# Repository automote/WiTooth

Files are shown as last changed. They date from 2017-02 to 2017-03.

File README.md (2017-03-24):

# WiTooth

The WiTooth is based on Espressif ESP32 WiFi-BT-BLE SoC (System on Chip), ESP32 contains two low-power Xtensa® 32-bit LX6 microprocessors running at 80 MHz. Features include:

 * Integrated 802.11 BGN WiFi transceiver
 * Integrated dual-mode Bluetooth (classic and BLE)
 * Dual-core Tensilica LX6 microprocessor
 * Up to 240MHz clock frequency
 * 520kB internal SRAM
 * 10-electrode capacitive touch support
 * Hardware accelerated encryption (AES, SHA2, ECC, RSA-4096)
 * 2.2 to 3.6V operating range
 * 2.5 µA deep sleep current
 * 3 SPI, 2 I2C, 2 UART
 * 16 PWM outputs
 * 2 DAC
 * 2 I2S
 * 18 analog-to-digital converter (ADC) channels
 
## Platform Features

 * Compatible with Arduino IDE
 * USB powered
 * CP2102 USB-to-UART Bridge
 * Extended breadboard compatible headers
 * UART, SPI, I2C
 * On-board RESET

## Changelog
 - v1.1
	+ Grounding via added
	+ Version bumped to 1.1
 - v1.0
	+ Updated 2N3904 symbol and footprint
	+ removed JTAG headers
 
## Maintainers

The WiTooth is maintained by thingTronics Innovations.

Main contributor:
 * Manohar Bompella @<manohar.bompella@thingtronics.com>
 * Poornima Nagesh @<poornima.nagesh@thingtronics.com>
 * Lovelesh Patel @<lovelesh.patel@thingtronics.com>

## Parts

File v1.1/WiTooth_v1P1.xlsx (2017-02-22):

Reference | Quantity | Value | Footprint | DESC | MFG_NAME | MPN | PCB Package | 1 | 100 | 500 | 1000 | 10 PCB | 100 PCB | 1000 PCB | Purchased cost for 100
C1 C4 | 2 | 10uF | Capacitors_SMD:C_0805_HandSoldering | Multilayer Ceramic Capacitors MLCC - SMD/SMT 10 uF 16V 10% | Yageo | AC0805KRX7R9BB103 | 805 | 3.5 | 2.1 | 2.1 | 2.1 | 7 | 4.2 | 4.2
C12 | 1 | 100uF | Capacitors_SMD:C_1206_HandSoldering | Multilayer Ceramic Capacitors MLCC - SMD/SMT 100 uF 16V 10% | Yageo | AC0805KRX7R9BB103 | 805 | 3.5 | 2.1 | 2.1 | 2.1 | 3.5 | 2.1 | 2.1
C13 C6 | 2 | 1uF | Capacitors_SMD:C_0805_HandSoldering | Multilayer Ceramic Capacitors MLCC - SMD/SMT 1 uF 16V 10% | Yageo | AC0805KRX7R9BB103 | 805 | 3.5 | 2.1 | 2.1 | 2.1 | 7 | 4.2 | 4.2
C2 | 1 | 0.1uF | Capacitors_SMD:C_0805_HandSoldering | Multilayer Ceramic Capacitors MLCC - SMD/SMT 0.1 uF 16V 10% | Yageo | AC0805KRX7R9BB103 | 805 | 3.5 | 2.1 | 2.1 | 2.1 | 3.5 | 2.1 | 2.1
C3 C5 | 2 | 47pF | Capacitors_SMD:C_0805_HandSoldering | Multilayer Ceramic Capacitors MLCC - SMD/SMT 47 pF 16V 10% | Yageo | AC0805KRX7R9BB103 | 805 | 3.5 | 2.1 | 2.1 | 2.1 | 7 | 4.2 | 4.2
C10 C14 C7 C8 | 4 | 1nF | Capacitors_SMD:C_0805_HandSoldering | Multilayer Ceramic Capacitors MLCC - SMD/SMT 1 nF 16V 10% | Yageo | AC0805KRX7R9BB103 | 805 | 3.5 | 2.1 | 2.1 | 2.1 | 14 | 8.4 | 8.4
C11 C9 | 2 | 27pF | Capacitors_SMD:C_0805_HandSoldering | Multilayer Ceramic Capacitors MLCC - SMD/SMT 27 pF 16V 10% | Yageo | AC0805KRX7R9BB103 | 805 | 3.5 | 2.1 | 2.1 | 2.1 | 7 | 4.2 | 4.2
D1 | 1 | PWR_GREEN | LEDs:LED_0805 | GREEN led for power indication | Kingbright | AP2012SRCPRV | 805 | 9.8 | 4.76 | 4.76 | 4.55 | 9.8 | 4.76 | 4.55
D2 D3 | 2 | YELLOW | LEDs:LED_0805 | Yellow led for Data Receiving indication | Kingbright | AP2012SRCPRV | 805 | 9.1 | 4.76 | 4.76 | 4.55 | 18.2 | 9.52 | 9.1
D4 | 1 | CONN_LED | LEDs:LED_0805 | RED led for Data Connection indication | Kingbright | AP2012SRCPRV | 805 | 9.8 | 4.76 | 4.76 | 4.55 | 9.8 | 4.76 | 4.55
D5 | 1 | USER_LED | LEDs:LED_0805 | GREEN led for User application | Kingbright | AP2012SRCPRV | 805 | 9.8 | 4.76 | 4.76 | 4.55 | 9.8 | 4.76 | 4.55
P1 | 1 | USB_A_MALE (DNM) | USB:usb-PCB_male | USB A MALE CONNECTOR pcb (DNM) | ******** | ********* |  |  |  |  |  | 0 | 0 | 0
P4 P5 | 2 | CONN_01X20 | Pin_Headers:Pin_Header_Straight_1x20_Pitch2.54mm | Worth Elekronik | 61300211121 |  | 8.4 | 7.42 | 6.3 | 6.23 | 6.23 | 14.84 | 12.6 | 12.46
Q1 Q2 | 2 | 2N3904-MMBT | TO_SOT_Packages_SMD:SOT-23_Handsoldering |  |  |  |  |  |  |  |  | 0 | 0 | 0
R10 | 1 | 5K | Resistors_SMD:R_0805_HandSoldering | Current Sense Resistors - SMD 0805 0.002ohm 1% AEC-Q200 | ROHM Semiconductor | PMR10EZPFV2L00 | 805 | 7.7 | 2.8 | 2.8 | 2.59 | 7.7 | 2.8 | 2.59
R11 R12 R13 R14 R7 | 5 | 470E | Resistors_SMD:R_0805_HandSoldering | Current Sense Resistors - SMD 0805 0.002ohm 1% AEC-Q200 | ROHM Semiconductor | PMR10EZPFV2L00 | 805 | 7.7 | 2.8 | 2.8 | 2.59 | 38.5 | 14 | 12.95
R15 R16 | 2 | 0E | Resistors_SMD:R_0805_HandSoldering | Current Sense Resistors - SMD 0805 0.002ohm 1% AEC-Q200 | ROHM Semiconductor | PMR10EZPFV2L00 | 805 | 7.7 | 2.8 | 2.8 | 2.59 | 15.4 | 5.6 | 5.18
R1 R2 R6 | 3 | 12K | Resistors_SMD:R_0805_HandSoldering | Current Sense Resistors - SMD 0805 0.002ohm 1% AEC-Q200 | ROHM Semiconductor | PMR10EZPFV2L00 | 805 | 7.7 | 2.8 | 2.8 | 2.59 | 23.1 | 8.4 | 7.77
R4 R8 R9 | 3 | 1K | Resistors_SMD:R_0805_HandSoldering | Current Sense Resistors - SMD 0805 0.002ohm 1% AEC-Q200 | ROHM Semiconductor | PMR10EZPFV2L00 | 805 | 7.7 | 2.8 | 2.8 | 2.59 | 23.1 | 8.4 | 7.77
R3 R5 | 2 | 27E | Resistors_SMD:R_0805_HandSoldering | Current Sense Resistors - SMD 0805 0.002ohm 1% AEC-Q200 | ROHM Semiconductor | PMR10EZPFV2L00 | 805 | 7.7 | 2.8 | 2.8 | 2.59 | 15.4 | 5.6 | 5.18
SW1 | 1 | RESET | switches:SW_SPST_B3U-1000P_SUNROM | TACTILE SWITCH 3X4X2MM SMD 2-PIN | SUNROM | 4982 | SMD | 4 | 3.6 | 3.6 | 3.6 | 4 | 3.6 | 3.6
SW2 | 1 | BOOT | switches:SW_SPST_B3U-1000P_SUNROM | TACTILE SWITCH 3X4X2MM SMD 2-PIN | SUNROM | 4982 | SMD | 4 | 3.6 | 3.6 | 3.6 | 4 | 3.6 | 3.6
SW3 | 1 | USER_SW | switches:SW_SPST_B3U-1000P_SUNROM | TACTILE SWITCH 3X4X2MM SMD 2-PIN | SUNROM | 4982 | SMD | 4 | 3.6 | 3.6 | 3.6 | 4 | 3.6 | 3.6
U1 | 1 | AMS1117-3V3 | TO_SOT_Packages_SMD:SOT-223 | LM1117 800-mA Low-Dropout Linear Regulator | Texas Instruments | LM1117 | SOT-233 | 9 | 6 | 4 | 3 | 9 | 6 | 3
U2 | 1 | CP2102 | smt-qfn:QFN-28-1EP_5x5mm_Pitch0.5mm | Single-Chip USB to UART Data Transfer | Silicon Labs | CP2102-GM | QFN-28 | 90 | 85 | 80 | 70 | 90 | 85 | 70
U3 | 1 | ESP-32_WROOM32_Rectangle | ESP-32:ESP32-WROOM_SMALLER_FOOTPRINT | ESP32-WROOM wifi Chip | WROOM |  |  | 650 | 650 | 650 | 600 | 650 | 650 | 600
Y1 | 1 | Crystal | Crystals:Crystal_SMD_0603-2pin_6.0x3.5mm_HandSoldering | 32.768 Khz RTC Crystals | SUNROM | 3964 | SMD | 15 | 13.5 | 13.5 | 13.5 | 15 | 13.5 | 13.5
 |  |  |  |  |  |  |  |  |  |  | TOTAL | 1010.64 | 875.9 | 803.35
 |  |  |  |  |  |  |  |  |  |  |  | 350
 |  |  |  |  |  |  |  |  |  |  |  | 1510.64

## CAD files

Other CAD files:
v1.0/MECH/cover.CATpart.CATPart
v1.0/MECH/switch.CATPart
v1.0/MECH/upper_by_part.CATPart

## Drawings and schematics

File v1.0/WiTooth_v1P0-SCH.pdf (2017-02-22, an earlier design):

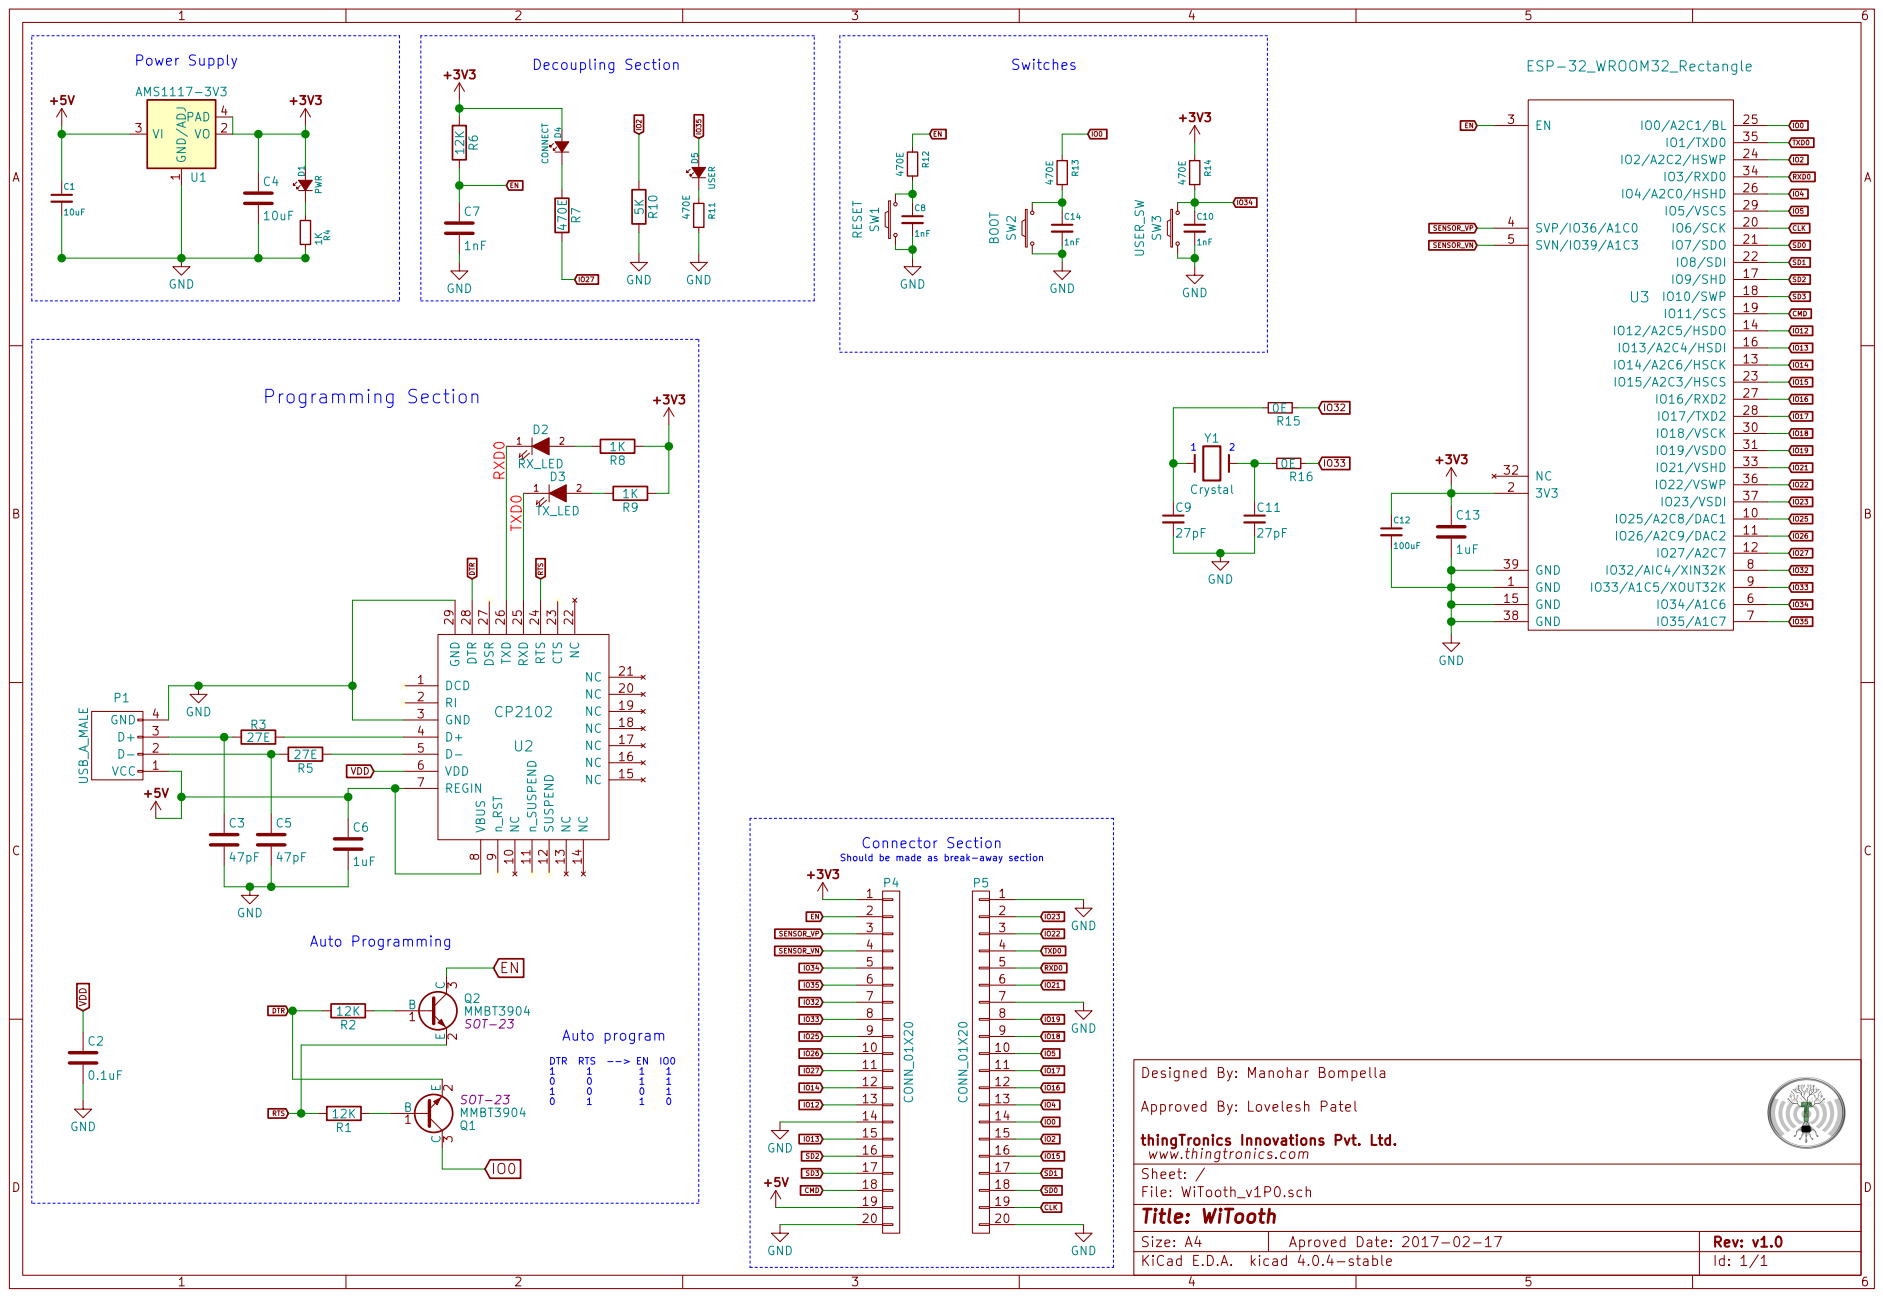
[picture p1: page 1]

Should be made as break-away section Programming Section

9 NC 10 NC 20 n_SUSPEND 11 NC 21 SUSPEND 12 NC 22 NC 13 CTS 23 NC 14 RTS 24 NC 15 RXD 25 NC 16 TXD 26 NC 17 DSR 27 NC 18 DTR 28 NC 19 GND 29 U2 CP2102 R5

Approved By: Lovelesh Patel

thingTronics Innovations Pvt. Ltd.
File: WiTooth_v1P0.sch Sheet: / www.thingtronics.com

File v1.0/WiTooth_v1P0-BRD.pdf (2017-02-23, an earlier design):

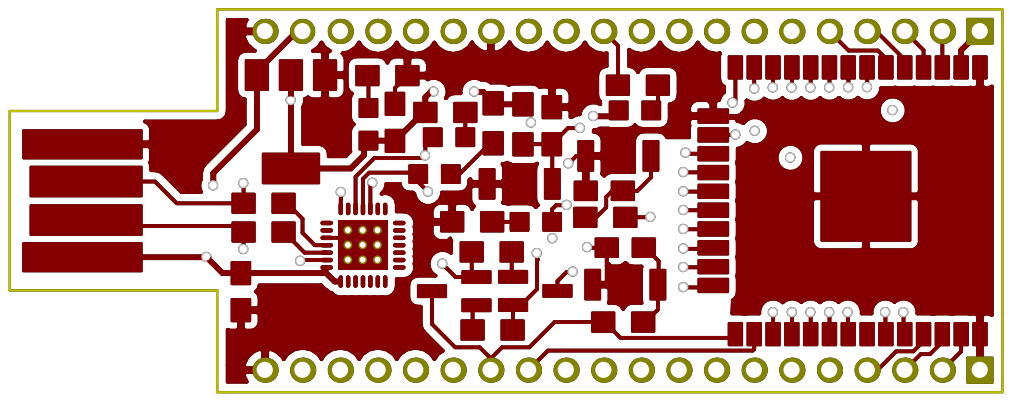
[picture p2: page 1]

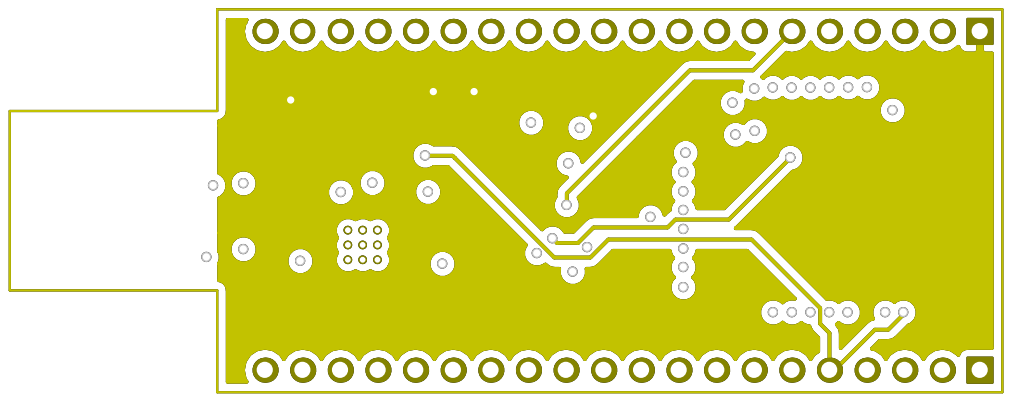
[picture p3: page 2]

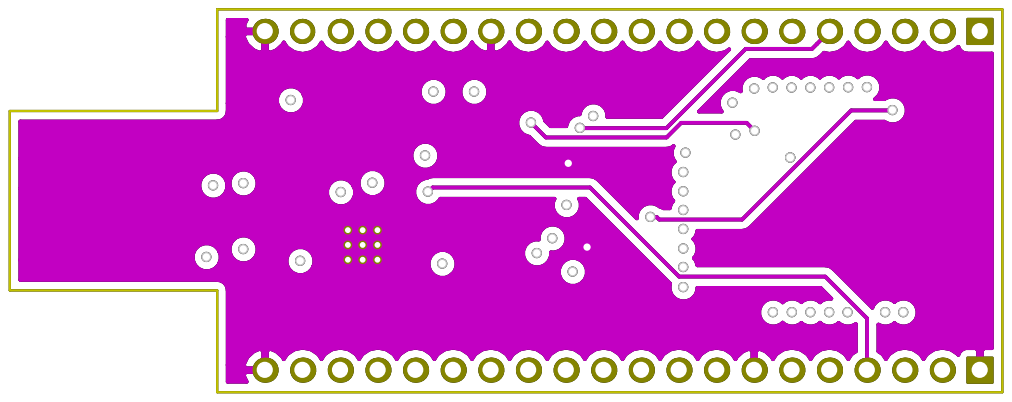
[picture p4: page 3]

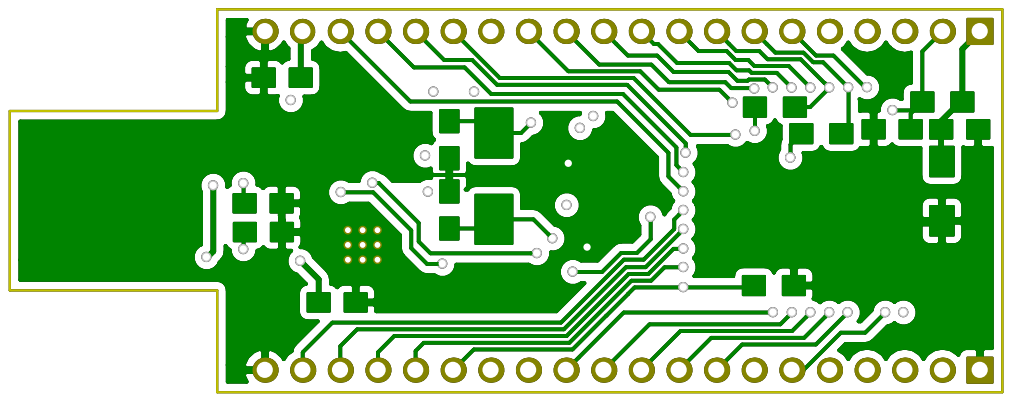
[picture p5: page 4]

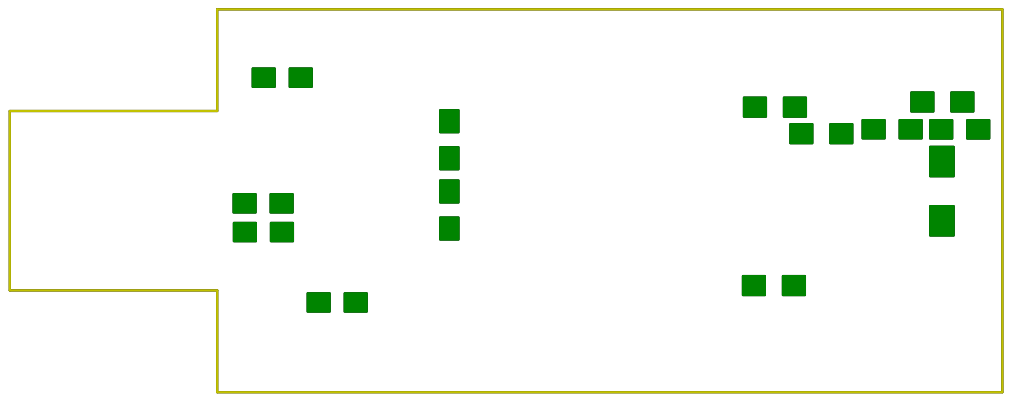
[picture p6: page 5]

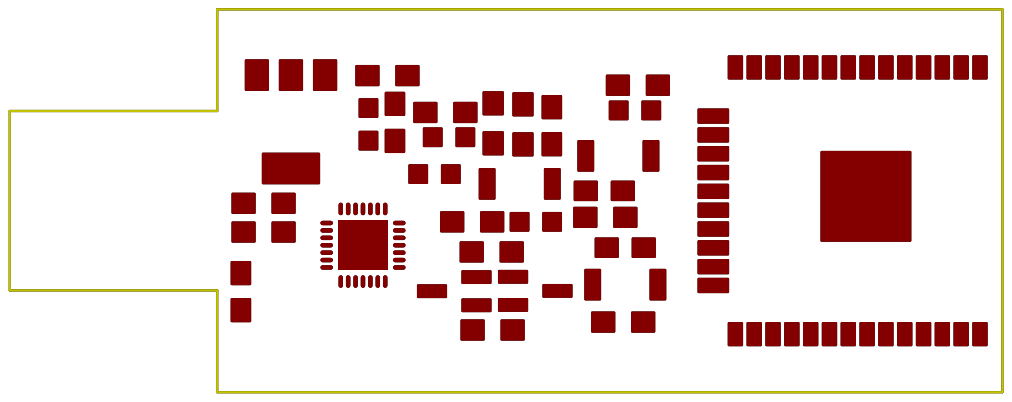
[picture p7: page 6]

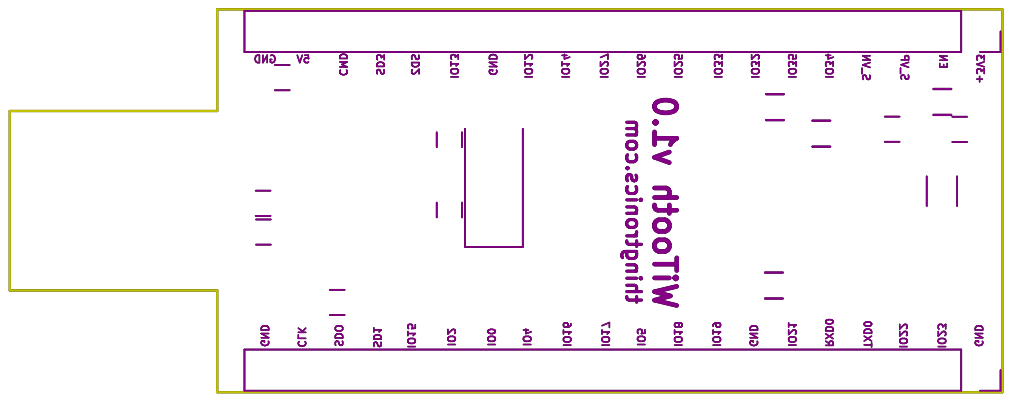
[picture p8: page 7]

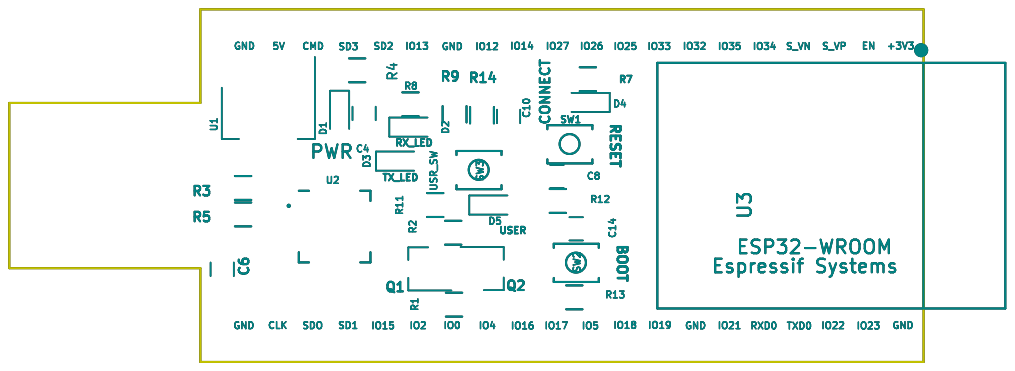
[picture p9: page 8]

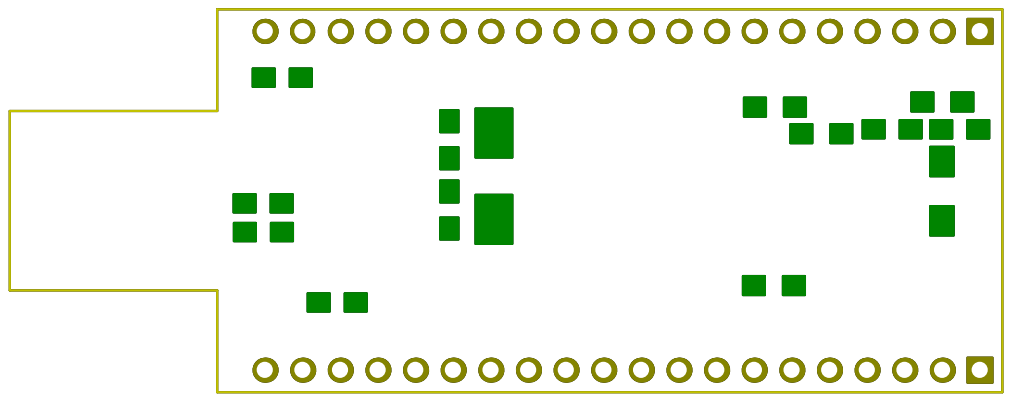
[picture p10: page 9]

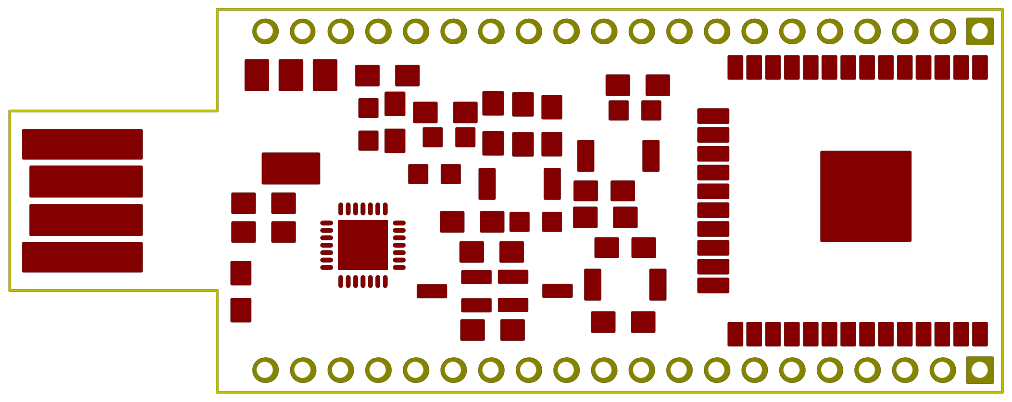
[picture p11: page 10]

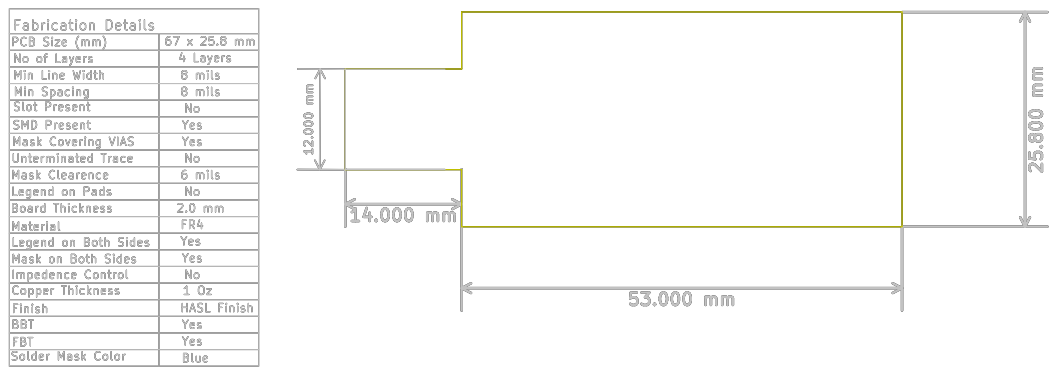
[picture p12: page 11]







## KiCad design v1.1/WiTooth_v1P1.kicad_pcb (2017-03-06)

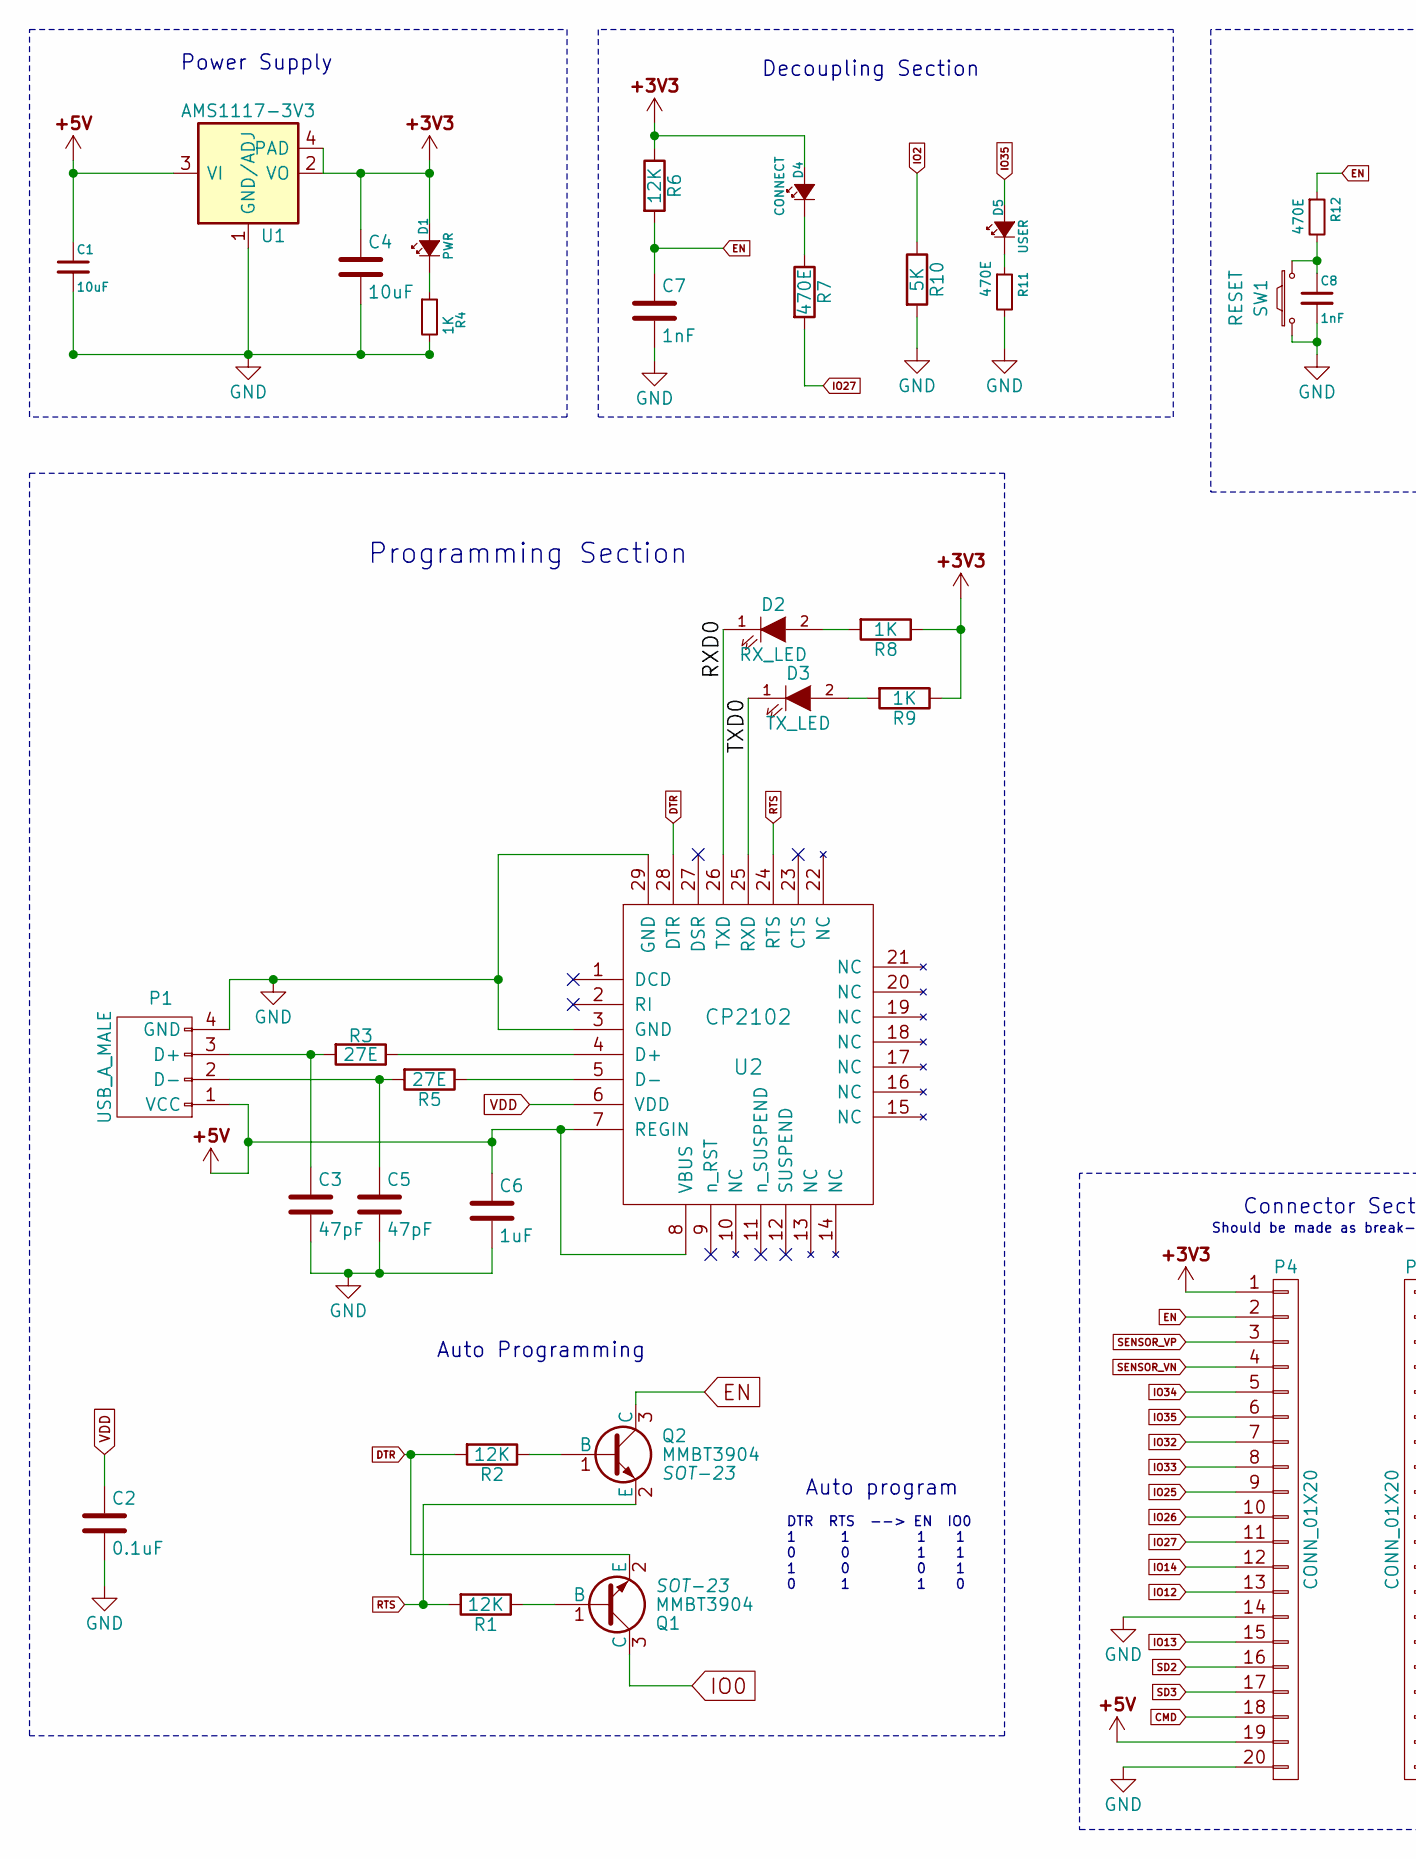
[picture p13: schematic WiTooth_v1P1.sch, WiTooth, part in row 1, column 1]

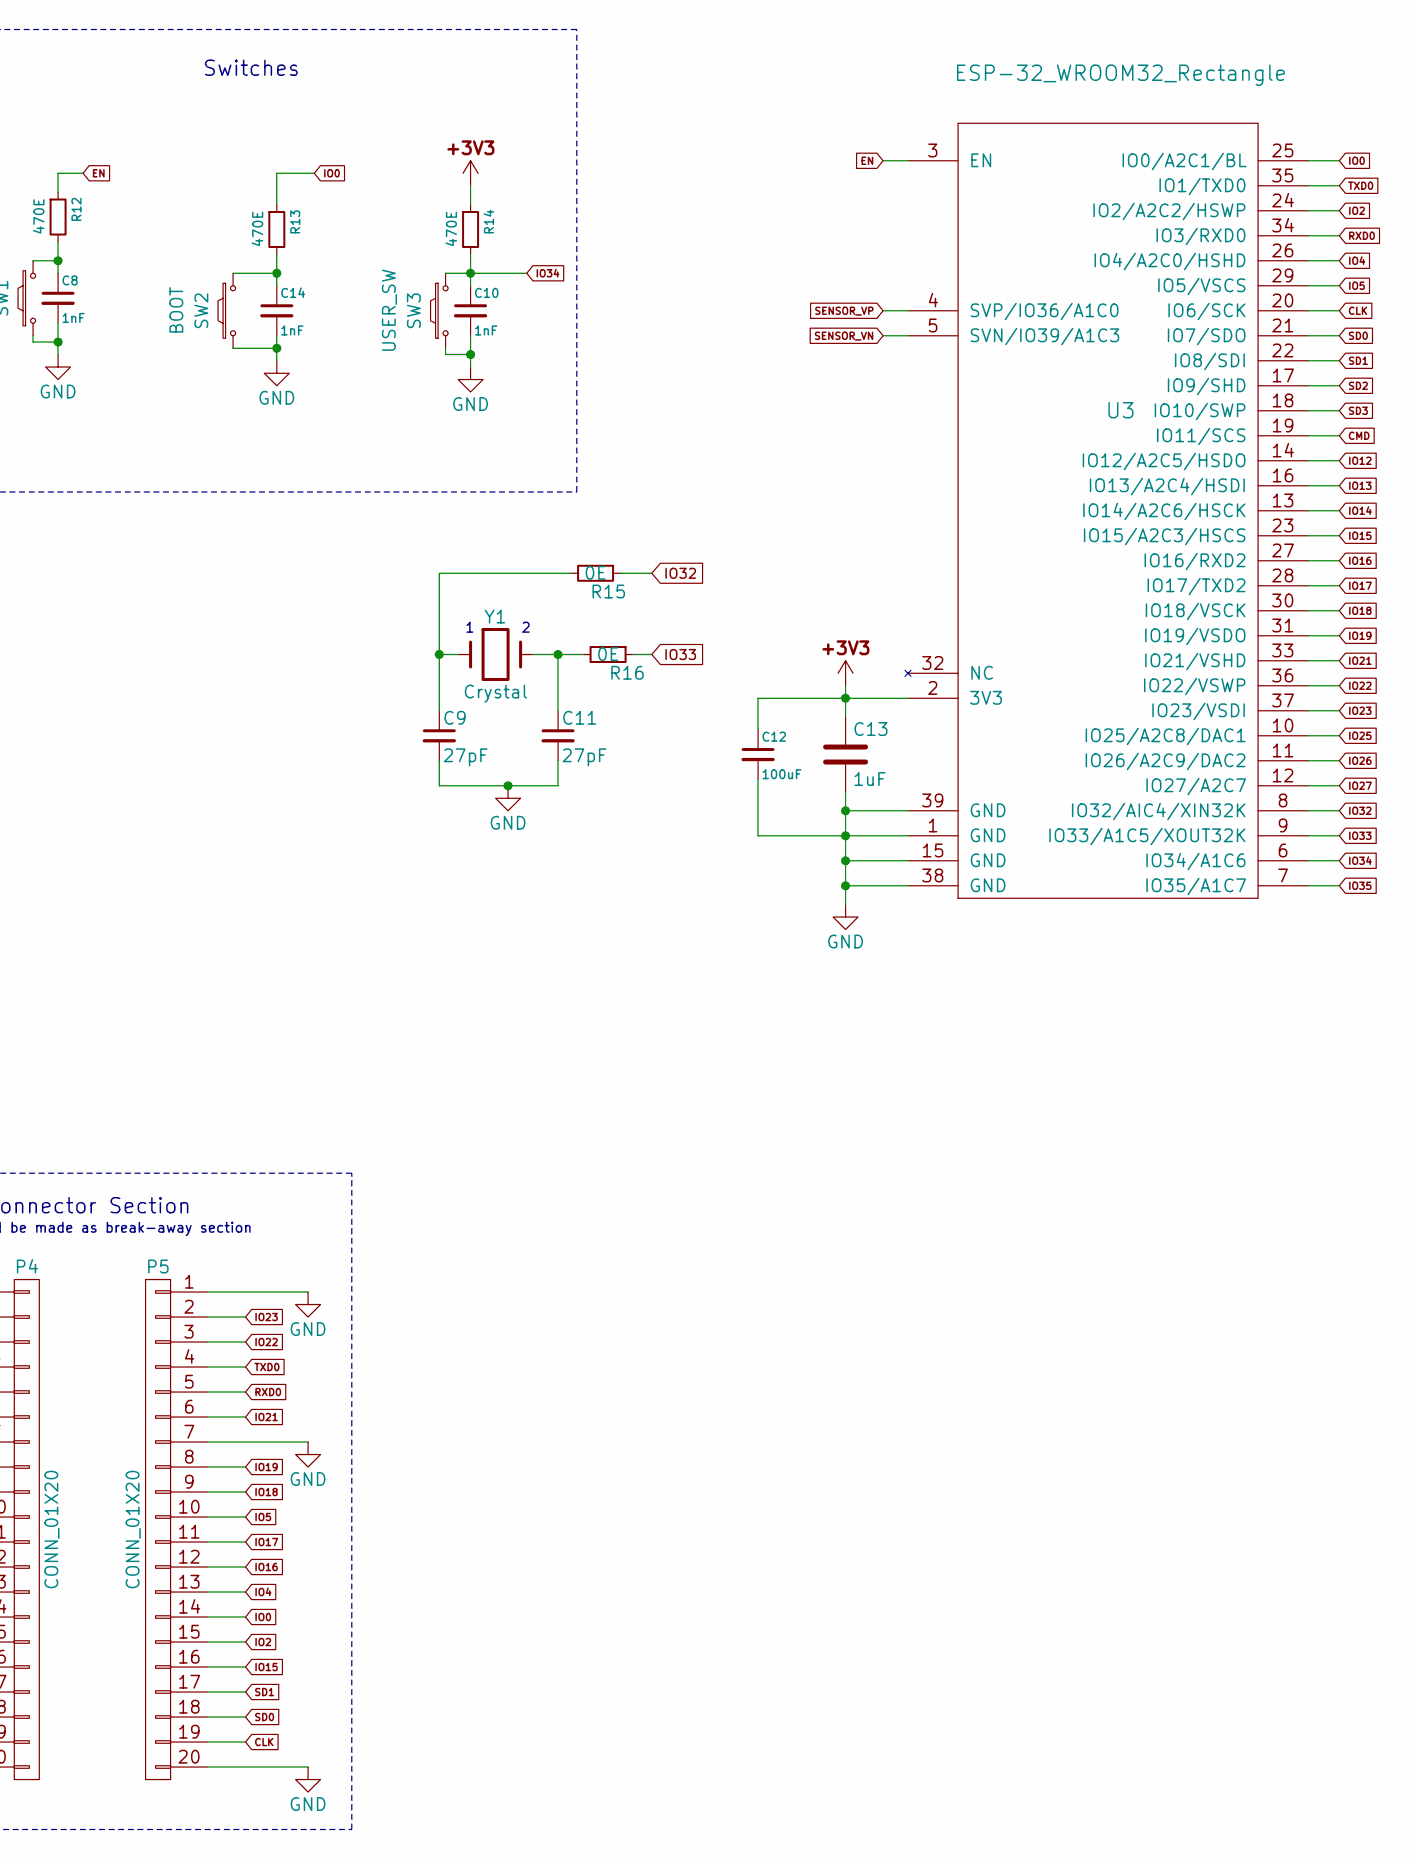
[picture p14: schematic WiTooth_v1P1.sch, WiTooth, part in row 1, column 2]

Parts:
C1, C4: 10uF; C_0805_HandSoldering
C2: 0.1uF; C_0805_HandSoldering
C3, C5: 47pF; C_0805_HandSoldering
C6, C13: 1uF; C_0805_HandSoldering
C7, C8, C10, C14: 1nF; C_0805_HandSoldering
C9, C11: 27pF; C_0805_HandSoldering
C12: 100uF; C_1206_HandSoldering
D1: PWR; LED_0805
D2: RX_LED; LED_0805
D3: TX_LED; LED_0805
D4: CONNECT; LED_0805
D5: USER; LED_0805
P1: USB_A_MALE; usb-PCB_male; MPN *********
P4, P5: CONN_01X20; Pin_Header_Straight_1x20_Pitch2.54mm
Q1, Q2: MMBT3904; SOT-23
R1, R2, R6: 12K; R_0805_HandSoldering
R3, R5: 27E; R_0805_HandSoldering
R4, R8, R9: 1K; R_0805_HandSoldering
R7, R11, R12, R13, R14: 470E; R_0805_HandSoldering
R10: 5K; R_0805_HandSoldering
R15, R16: 0E; R_0805_HandSoldering
SW1: RESET; SW_SPST_B3U-1000P_SUNROM
SW2: BOOT; SW_SPST_B3U-1000P_SUNROM
SW3: USER_SW; SW_SPST_B3U-1000P_SUNROM
U1: AMS1117-3V3; SOT-223; MPN LM1117
U2: CP2102; QFN-28-1EP_5x5mm_Pitch0.5mm
U3: ESP-32_WROOM32_Rectangle; ESP32-WROOM_SMALLER_FOOTPRINT
Y1: Crystal; Crystal_SMD_0603-2pin_6.0x3.5mm_HandSoldering

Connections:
+3V3: C4.1, C12.1, C13.1, D1.2 (A), D4.2 (A), P4.1, R6.1, R8.1, R9.1, R14.1, U1.2 (VO), U1.4 (PAD), U3.2 (3V3)
+5V: C1.1, C6.1, P1.1 (VCC), P4.19, U1.3 (VI), U2.7 (REGIN), U2.8 (VBUS)
CLK: P5.19, U3.20 (IO6/SCK)
CMD: P4.18, U3.19 (IO11/SCS)
DTR: Q1.2 (E), R2.2, U2.28 (DTR)
EN: C7.1, P4.2, Q2.3 (C), R6.2, R12.1, U3.3 (EN)
GND: C1.2, C2.2, C3.2, C4.2, C5.2, C6.2, C7.2, C8.2, C9.2, C10.2, C11.2, C12.2, C13.2, C14.2, P1.4 (GND), P4.14, P4.20, P5.1, P5.7, P5.20, R4.2, R10.2, R11.2, SW1.1, SW2.1, SW3.1, U1.1 (GND/ADJ), U2.3 (GND), U2.29 (GND), U3.1 (GND), U3.15 (GND), U3.38 (GND), U3.39 (GND)
IO0: P5.14, Q1.3 (C), R13.1, U3.25 (IO0/A2C1/BL)
IO2: P5.15, R10.1, U3.24 (IO2/A2C2/HSWP)
IO4: P5.13, U3.26 (IO4/A2C0/HSHD)
IO5: P5.10, U3.29 (IO5/VSCS)
IO12: P4.13, U3.14 (IO12/A2C5/HSDO)
IO13: P4.15, U3.16 (IO13/A2C4/HSDI)
IO14: P4.12, U3.13 (IO14/A2C6/HSCK)
IO15: P5.16, U3.23 (IO15/A2C3/HSCS)
IO16: P5.12, U3.27 (IO16/RXD2)
IO17: P5.11, U3.28 (IO17/TXD2)
IO18: P5.9, U3.30 (IO18/VSCK)
IO19: P5.8, U3.31 (IO19/VSDO)
IO21: P5.6, U3.33 (IO21/VSHD)
IO22: P5.3, U3.36 (IO22/VSWP)
IO23: P5.2, U3.37 (IO23/VSDI)
IO25: P4.9, U3.10 (IO25/A2C8/DAC1)
IO26: P4.10, U3.11 (IO26/A2C9/DAC2)
IO27: P4.11, R7.2, U3.12 (IO27/A2C7)
IO32: P4.7, R15.1, U3.8 (IO32/AIC4/XIN32K)
IO33: P4.8, R16.1, U3.9 (IO33/A1C5/XOUT32K)
IO34: C10.1, P4.5, R14.2, SW3.2, U3.6 (IO34/A1C6)
IO35: D5.2 (A), P4.6, U3.7 (IO35/A1C7)
unnamed: C3.1, P1.3 (D+), R3.2
unnamed: C5.1, P1.2 (D-), R5.2
unnamed: C8.1, R12.2, SW1.2
unnamed: C9.1, R15.2, Y1.1
unnamed: C11.1, R16.2, Y1.2
unnamed: C14.1, R13.2, SW2.2
unnamed: D1.1 (K), R4.1
unnamed: D2.2 (A), R8.2
unnamed: D3.2 (A), R9.2
unnamed: D4.1 (K), R7.1
unnamed: D5.1 (K), R11.1
unnamed: Q1.1 (B), R1.1
unnamed: Q2.1 (B), R2.1
unnamed: R3.1, U2.4 (D+)
unnamed: R5.1, U2.5 (D-)
RTS: Q2.2 (E), R1.2, U2.24 (RTS)
RXD0: D2.1 (K), P5.5, U2.26 (TXD), U3.34 (IO3/RXD0)
SD0: P5.18, U3.21 (IO7/SDO)
SD1: P5.17, U3.22 (IO8/SDI)
SD2: P4.16, U3.17 (IO9/SHD)
SD3: P4.17, U3.18 (IO10/SWP)
SENSOR_VN: P4.4, U3.5 (SVN/IO39/A1C3)
SENSOR_VP: P4.3, U3.4 (SVP/IO36/A1C0)
TXD0: D3.1 (K), P5.4, U2.25 (RXD), U3.35 (IO1/TXD0)
VDD: C2.1, U2.6 (VDD)

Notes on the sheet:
Switches
Power Supply
Connector Section
Decoupling Section
Should be made as break-away section
Programming Section
Auto Programming
Auto program
DTR RTS --> EN IO0 1 1 1 1 0 0 1 1 1 0 0 1 0 1 1 0

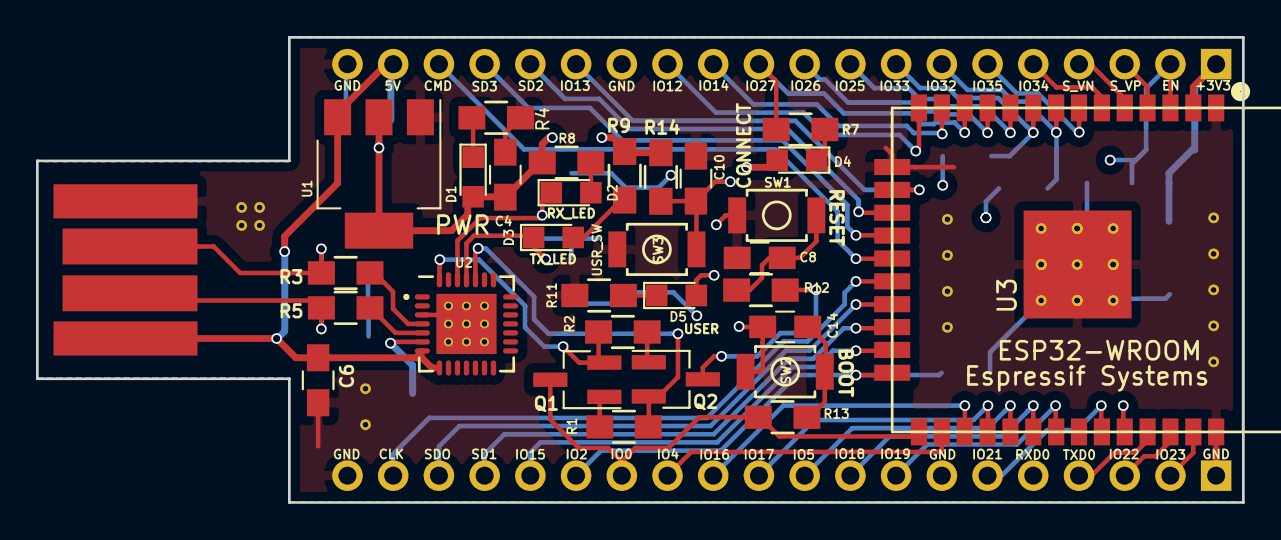
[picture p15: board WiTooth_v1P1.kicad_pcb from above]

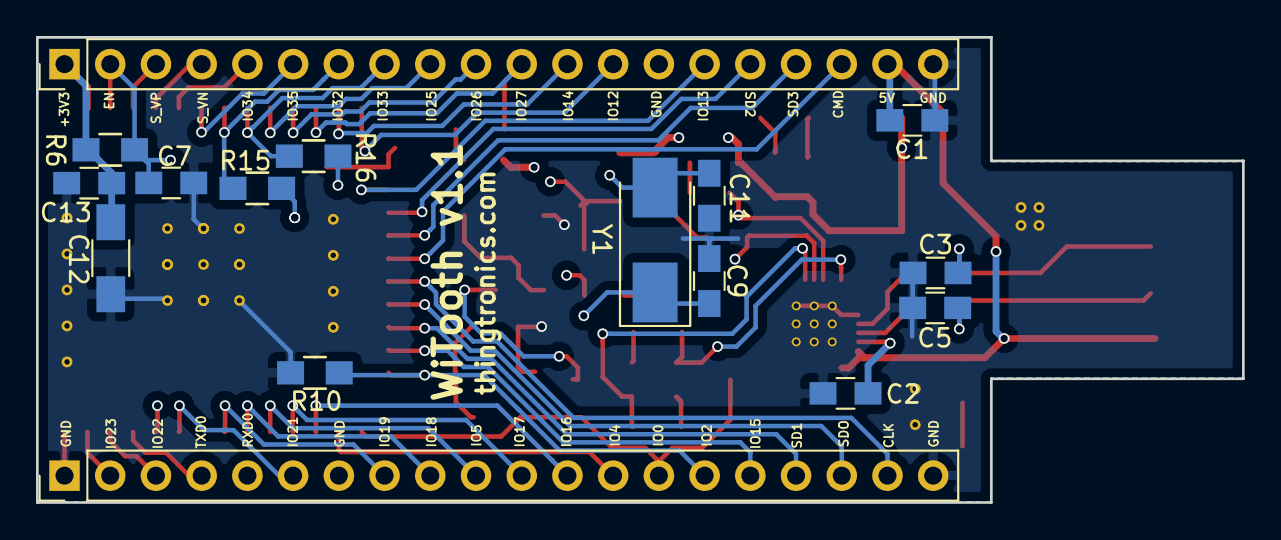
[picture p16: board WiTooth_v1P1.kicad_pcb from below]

Board: 4 copper layers, 67.0 x 25.8 mm, 47 parts (16 on the bottom side), 54 nets.

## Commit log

2017-02-17 Added images folder; schematic verified
    [WiTooth_v1P0.kicad_pcb, WiTooth_v1P0.sch]
2017-02-18 verified layout; ready for fab
    [WiTooth_v1P0-3V3.gbr, WiTooth_v1P0-B.Cu.gbr, WiTooth_v1P0-B.Fab.gbr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]
2017-02-18 BOM verified
    [WiTooth_v1P0.kicad_pcb, WiTooth_v1P0.sch]
2017-02-22 updated the 2N3904 npn transistor footprint
    [WiTooth_v1P0-3V3.gbr, WiTooth_v1P0-B.Cu.gbr, WiTooth_v1P0-B.Fab.gbr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]
2017-02-23 minor changes to DWGS.User file
    [WiTooth_v1P0.kicad_pcb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]
2017-03-06 bumped up the project to v1.1; added extra grounding in layout
    [WiTooth_v1P1.kicad_pcb, WiTooth_v1P1.sch, WiTooth_v1P1.xlsx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]
